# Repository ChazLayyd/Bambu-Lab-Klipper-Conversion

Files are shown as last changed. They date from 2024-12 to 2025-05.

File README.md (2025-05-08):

## Bambu Lab Klipper Conversion!

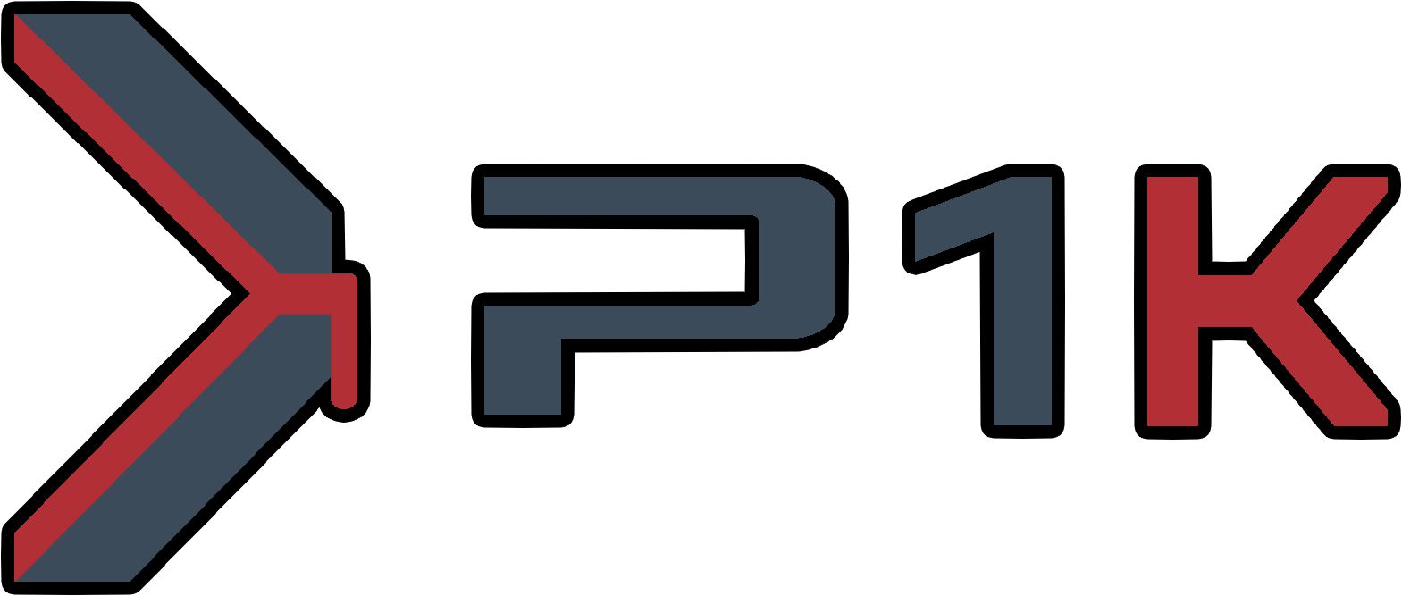
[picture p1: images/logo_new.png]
Klipper Logo


## Join the [**Community Discord!**](https://discord.gg/W6B5mBejuC)

## As requested multiple times- you can support the project on [**Ko-Fi**](https://ko-fi.com/chazmakes). It's not necessary, but if you want to help out then all support is greatly appreciated!

> [!Caution]
> This Project is in **BETA**, doing this conversion is fully at your own risk, I am not responsible for any damages done to your machine. This also will likely void your warranty.

Welcome to the Bambu Lab Klipper Conversion page! The project is in beta at the moment. This is a **non-destructive (PCB Only)**, or **destructive** upgrade path to [**Klipper**](https://www.klipper3d.org/), on a Bambu Lab P1 (or X1, untested). This means replacing the existing electronics with open-source hardware. A custom PCB has been designed to make everything plug and play with the fans, heatbed etc. The project runs on a fork of Klipper known as [**Kalico**](https://github.com/KalicoCrew/kalico), previously known as DangerKlipper. Make sure to get yourself familiarized with [**The Official Klipper Docs**](https://www.klipper3d.org/) and [**The Kalico Docs**](https://github.com/KalicoCrew/kalico/tree/main/docs)

You can find the BOM [**here**](https://docs.google.com/spreadsheets/d/187OusyREO98zsinT2Vspcr3hRtGYJvgfUr3D4DhnsbQ/edit?usp=sharing).

Find extensive documentation [**here**](https://docs.chazmakes.com/)!

The current release is <ins>**0.1** </ins>

## What works? (as of release <ins>**0.1**</ins>)
- ✓ The full hotend and extruder assembly
- ✓ Heatbed control with the Stock SSR
- ✓ The entire motion system is unchanged
- ✓ All fans work if wired correctly (PWM and Tach control needs to be added)
- ✓ Bambu Lab AMS does work via the [**OpenAMS project**](https://github.com/OpenAMSOrg)

## What doesn't work? (as of release <ins>**0.1**</ins>)
- ✖ Load cell probing (Replaced for now with a Biqu Microprobe), but a custom board is in the works.
- ✖ Webcam (You can purchase the X1C camera and wire it up as a USB camera)
- ✖ Stock display
- ✖ Toolhead boards
- ✖ Filament runout detection
- ✖ Not everything is plug and play. There is a PCB design available to make this non destructive You will need to splice on extension cables + JST XH 2.54 or DuPont 2.54 connectors.

## Why?

At first, this was a joke. More of a "why not" sort of thing. But as time went on, I really started to think of the benefits of putting Klipper on this machine. All my other printers run on Klipper.. so why not make the Bambu also run on Klipper! It provides a great platform for modding, such as adding extra fans, a nicer webcam, maybe some better controlled neopixel lighting, fully custom toolheads.. And most importantly, having the heatbed capable of running at 110C! Whatever you can think of, you can do it with this platform. It also completely eliminates the Bambu Cloud, allowing you to run everything locally, or even use your own cloud service.. Who else loves privacy?!

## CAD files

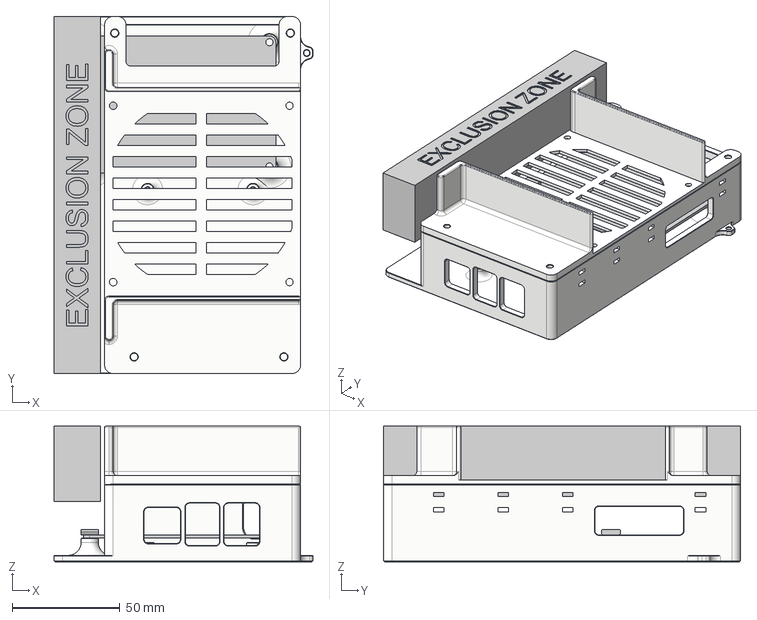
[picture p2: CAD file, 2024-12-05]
CAD/(UNTESTED)Fly D5 & Pi 3B etc.step
120.4 x 166.0 x 63.0 mm

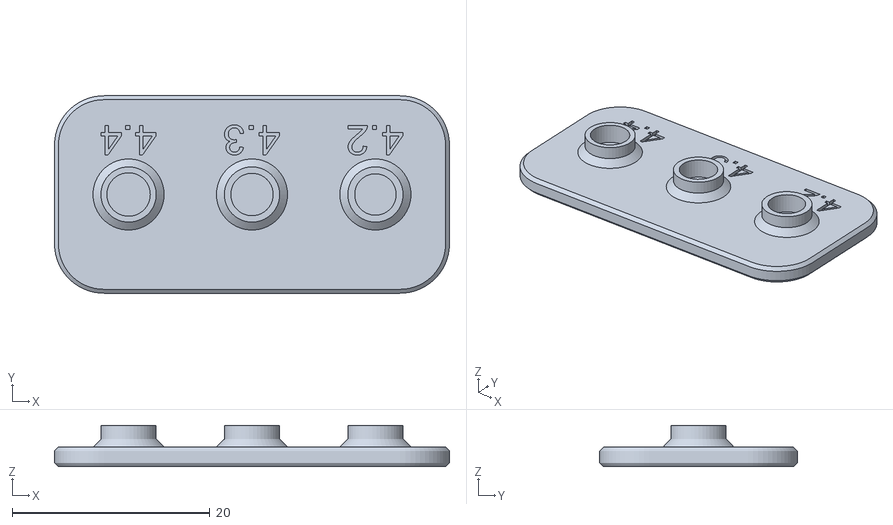
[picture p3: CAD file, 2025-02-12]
STL/Tolerance Test 4.2-4.4.stl
40.0 x 20.0 x 4.20

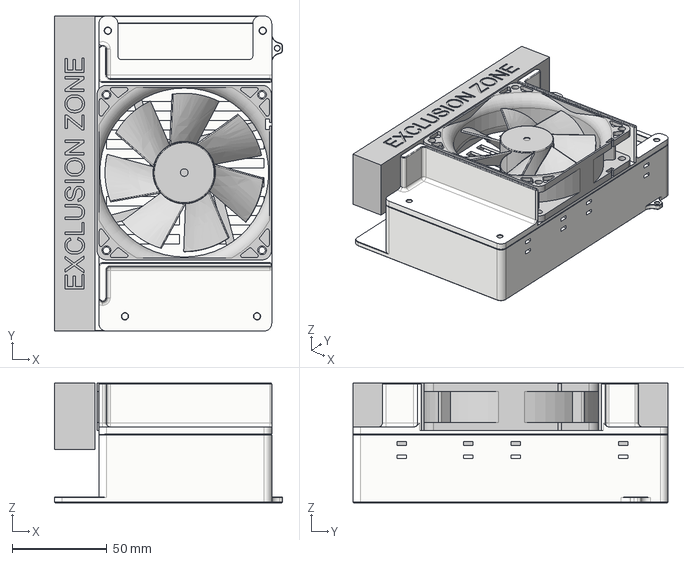
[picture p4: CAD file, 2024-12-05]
CAD/Generic Template Electronics Box.step
120.4 x 166.0 x 63.0 mm
Вентилятор 92мм Titan TFD-9225L12Z корпус
Вентилятор 92мм Titan TFD-9225L12Z крыльчатка

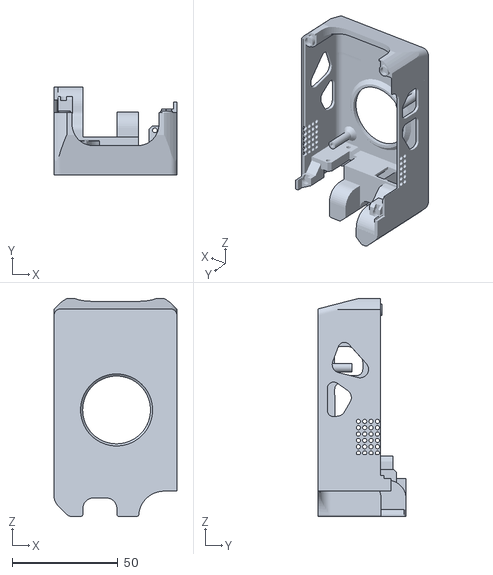
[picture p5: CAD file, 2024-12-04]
STL/Toolhead P1 NO LOGO.stl
58.0 x 41.8 x 103.0

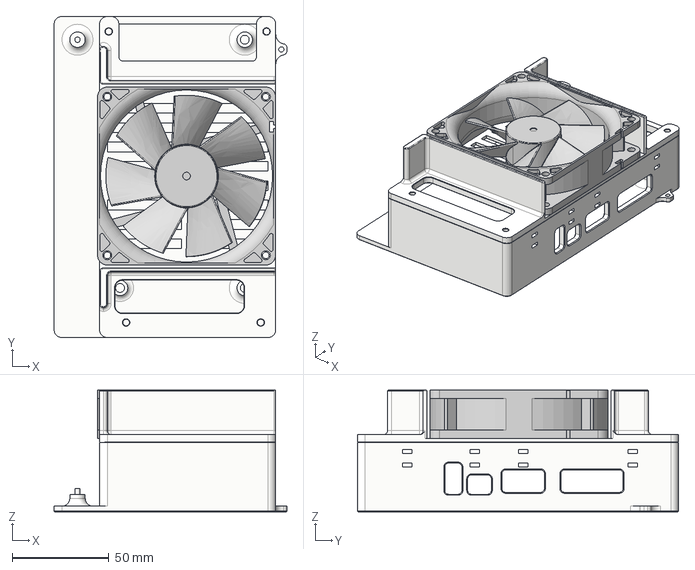
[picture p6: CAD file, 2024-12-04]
CAD/Manta M5P Electronics Box (BETA 0.1).step
120.4 x 166.0 x 63.0 mm
Вентилятор 92мм Titan TFD-9225L12Z корпус
Вентилятор 92мм Titan TFD-9225L12Z крыльчатка

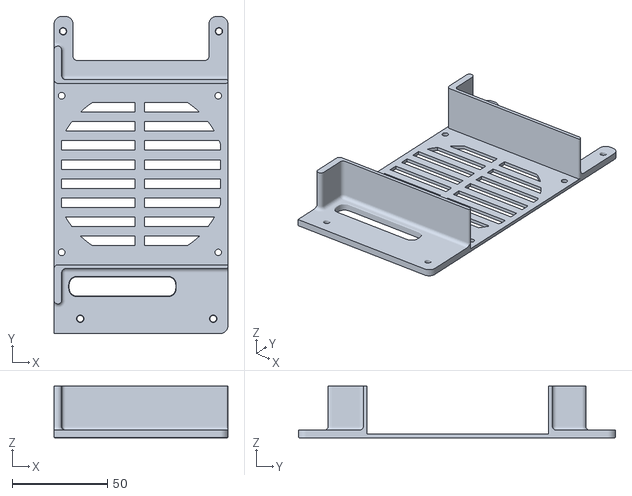
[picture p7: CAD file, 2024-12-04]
STL/Electronics Box Lid.stl
91.1 x 166.0 x 27.0

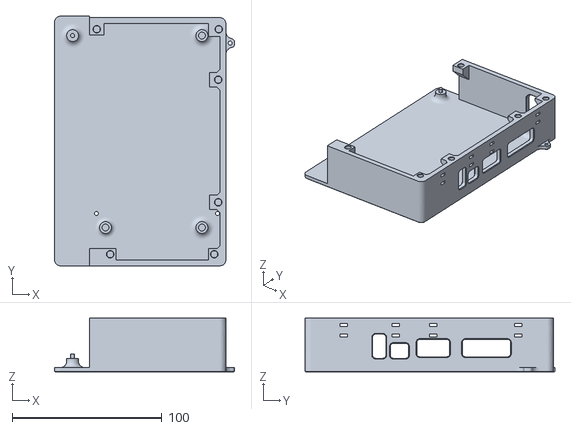
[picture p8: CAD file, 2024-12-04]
STL/Electronics Box M5P Beta 0.1.stl
120.4 x 167.0 x 36.0

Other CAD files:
CAD/Toolhead (BETA 0.1).step
STL/Toolhead P1.stl

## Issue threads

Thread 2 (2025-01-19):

Not an Issue, possibility of working on a1

DevCyclonekittenTriHex, 2025-01-19:
I am planning to attempt this on a bbl a1 printer.

My simple questions would be as follows:

- do p1 and a1 use the same motor connectors.

- do p1 and a1 use the same heat bed connector.

That's it. If I am successful, i will explain my method and possibly you can update the GitHub page to include an a1 / a1m section.

ChazLayyd, 2025-01-19:
Hey there, the A1 can probably be converted. I don't own one to tear it down. The P1 and A1 use the same bed but not sure about connectors sorry.

Closed 2025-01-19.

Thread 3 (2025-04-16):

original circuit boards

john-clark, 2025-04-16:
Why are you replacing the circuit boards? Why not flash the original boards?

ChazLayyd, 2025-04-17:
The original boards run on ESP32 and Spintrol chips which cannot be re-flashed. People have tried to do this but it is simply impossible.

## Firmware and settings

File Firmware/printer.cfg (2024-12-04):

# THIS IS A BETA PRINTER.CFG FILE FOR THE BAMBU LAB P1 KLIPPER PROJECT ON A BIGTREETECH MANTA M5P, THIS CFG MAY NOT BE FINAL. USE AT YOUR OWN RISK.

# This file contains common pin mappings for the BIGTREETECH Manta M5P
# To use this config, the firmware should be compiled for the
# STM32G0B1 with a "8KiB bootloader" "8 MHz crystal"
# and "USB (on PA11/PA12)" or "CAN bus (on PD0/PD1)".

# See docs/Config_Reference.md for a description of parameters.

########################################
# Printer and MCU configuration
########################################

[include mainsail.cfg]
[include macros.cfg]
[exclude_object]
[include KAMP_Settings.cfg]
#[include neopixel.cfg]
#[include moonraker_obico_macros.cfg]

[mcu host]
serial: /tmp/klipper_host_mcu

[mcu]
serial: /dev/serial/by-id/usb-Klipper_stm32g0b1xx_260049001950425938323120-if00

[printer]
kinematics: corexy
max_velocity: 400
max_accel: 15000
max_z_velocity: 15
max_z_accel: 100

[input_shaper]
shaper_freq_x: 66.2
shaper_type_x: mzv
shaper_freq_y: 56.0
shaper_type_y: mzv

#[force_move]
#enable_force_move: True

########################################
# Stepper Motor Configuration
########################################

[stepper_x]
step_pin: PA10
dir_pin: !PA14
enable_pin: !PA13
microsteps: 16
rotation_distance: 40
endstop_pin: tmc2209_stepper_x:virtual_endstop
position_endstop: 256
position_max: 256
homing_speed: 60
homing_retract_dist: 5

[stepper_y]
step_pin: PC6
dir_pin: !PC7
enable_pin: !PA9
microsteps: 16
rotation_distance: 40
endstop_pin: tmc2209_stepper_y:virtual_endstop
position_endstop: 0
position_max: 267
homing_speed: 60
homing_retract_dist: 0

[stepper_z]
step_pin: PB12
dir_pin: !PB11
enable_pin: !PA8
microsteps: 16
rotation_distance: 8
gear_ratio: 3:1
endstop_pin: probe:z_virtual_endstop
#position_endstop: 0.0
position_max: 250
position_min: -5
homing_speed: 10
second_homing_speed: 5
full_steps_per_rotation: 200

[extruder]
step_pin: PB0
dir_pin: !PB1
enable_pin: !PC4
microsteps: 16
rotation_distance: 0.825
gear_ratio: 9:53
nozzle_diameter: 0.400
filament_diameter: 1.750
heater_pin: PC5
sensor_type: ATC Semitec 104NT-4-R025H42G
sensor_pin: PA1
#control: mpc
heater_power: 48
cooling_fan: fan
filament_diameter: 1.75
filament_density: 1.25
filament_heat_capacity: 1.8 
#pid_Kp: 33.513
#pid_Ki: 14.895
#pid_Kd: 18.851
min_temp: -100
max_temp: 280
max_extrude_only_distance: 100
max_extrude_cross_section: 50

[tmc2209 stepper_x]
uart_pin: PD8
run_current: 1.2
hold_current: 0.6
diag_pin: ^PD2
driver_SGTHRS: 110
interpolate: True
stealthchop_threshold: 0
sense_resistor: 0.110

[tmc2209 stepper_y]
uart_pin: PB10
run_current: 1.2
hold_current: 0.6
diag_pin: ^PC3
driver_SGTHRS: 110
interpolate: True
stealthchop_threshold: 0
sense_resistor: 0.110

[tmc2209 stepper_z]
uart_pin: PB2
run_current: 0.500
hold_current: 0.5
diag_pin: PC3
interpolate: True
stealthchop_threshold: 0
sense_resistor: 0.110

[tmc2209 extruder]
uart_pin: PA6
run_current: 0.600
diag_pin: PC2
interpolate: False
sense_resistor: 0.110

########################################
# Bed Settings
########################################

[heater_bed]
heater_pin: PA7
sensor_type: Generic 3950
sensor_pin: PA0
#control: pid
#pid_Kp: 55
#pid_Ki: 2
#pid_Kd: 100
min_temp: 0
max_temp: 125
max_power: 0.5

########################################
# Fan Settings
########################################

## DEFINE THIS IF YOU PLAN TO USE THE AUX FAN.
#[fan_generic aux_fan]
#pin: host:gpiochip0/gpio17   # PWM pin for fan speed control
#max_power: 1.0        # Set maximum power to 100%
#cycle_time: 0.01        # Smooth PWM frequency
#shutdown_speed: 0       # Turn off the fan during shutdown

[fan] # Parts Cooling Fan
pin: PA3

[heater_fan Heatbreak_Cooling] # Heatbreak Cooling On The Hotend
pin: PA4
heater: extruder
heater_temp: 50.0
fan_speed: 1.0

[board_pins]
aliases:
    # EXP1 header
    EXP1_1=PD5, EXP1_3=PB3, EXP1_5=PB5, EXP1_7=PB7, EXP1_9=<GND>,
    EXP1_2=PD4,  EXP1_4=PD6, EXP1_6=PB4, EXP1_8=PB6, EXP1_10=<5V>,
    # EXP2 header
    EXP2_1=PB14, EXP2_3=PB8, EXP2_5=PC10, EXP2_7=PC12,  EXP2_9=<GND>,
    EXP2_2=PB13, EXP2_4=PB9, EXP2_6=PB15, EXP2_8=<RST>, EXP2_10=<NC>

# See the sample-lcd.cfg file for definitions of common LCD displays.

########################################
# Probe Settings (BIQU MICROPROBE)
########################################

[output_pin probe_enable]
pin: PC15
value: 0

[gcode_macro Probe_Deploy]
gcode:
  SET_PIN PIN=probe_enable VALUE=1

[gcode_macro Probe_Stow]
gcode:
  SET_PIN PIN=probe_enable VALUE=0

[probe]
pin: ^!PC13 # For V1 version, set to ^PC13 for high-level trigger; for V2 version, set to ^!PC13 for low-level trigger.
deactivate_on_each_sample: False
x_offset: 28.0 # Actual offset of the MicroProbe installation
y_offset: -15.0 # Actual offset of the MicroProbe installation
#z_offset: 0.0 # Actual offset of the MicroProbe installation
speed: 10
activate_gcode:
  Probe_Deploy
  G4 P500 # Allow 200 milliseconds for the probe to deploy
deactivate_gcode:
  Probe_Stow

########################################
# BED MESH, HOMING ETC.
########################################

[bed_mesh]
speed: 200
horizontal_move_z: 5
mesh_min: 38, 20
mesh_max: 238, 233
probe_count: 5, 5

[safe_z_home]
home_xy_position: 128, 128
speed: 200.0
z_hop: 10
z_hop_speed: 10.0

[screws_tilt_adjust]
screw1: 18, 45
screw1_name: front left screw
screw2: 200, 45
screw2_name: front right screw
screw3: 118, 230
screw3_name: rear right screw
horizontal_move_z: 5.
speed: 250.
screw_thread: CW-M5

########################################
# Other Settings / Unused
########################################

#[neopixel LED]
#pin: PC14
#chain_count:18
#   The number of Neopixel chips that are "daisy chained" to the
#   provided pin. The default is 1 (which indicates only a single
#   Neopixel is connected to the pin).
#color_order: GRB
#initial_RED: 0.5
#initial_GREEN: 0.0
#initial_BLUE: 0.5
#initial_WHITE: 1.0

#[neopixel my_neopixel2]
#pin: PC14

#[adxl345]
#cs_pin: PC0
#spi_bus: spi2

#[tmc2209 extruder1]
#uart_pin: PA6
#run_current: 0.600
#diag_pin:

#sensor_type:MAX31865
#sensor_pin: PA4
#spi_bus: spi1
#rtd_nominal_r: 100
#rtd_reference_r: 430
#rtd_num_of_wires: 2

#[filament_switch_sensor material_0]
#switch_pin: PC2

#[extruder1]
#step_pin: PB0
#dir_pin: PB1
#enable_pin: !PC4
#heater_pin: PA7
#sensor_pin: PA2
#...

# Proximity switch
#[probe]
#pin: PC15

#[bltouch]
#sensor_pin: PC13
#control_pin: PC15

#[heater_fan SoC_fan]
#pin: CB1: gpio79
#pin: RPI: gpio26

#*# <---------------------- SAVE_CONFIG ---------------------->
#*# DO NOT EDIT THIS BLOCK OR BELOW. The contents are auto-generated.
#*#
#*# [probe]
#*# z_offset = 1.610
#*#
#*# [bed_mesh default]
#*# version = 1
#*# points =
#*# 	  -0.015000, -0.015000, 0.004167
#*# 	  -0.028333, -0.039167, -0.008333
#*# 	  -0.030000, -0.047500, -0.015000
#*# x_count = 3
#*# y_count = 3
#*# mesh_x_pps = 2
#*# mesh_y_pps = 2
#*# algo = lagrange
#*# tension = 0.2
#*# min_x = 95.5
#*# max_x = 160.5
#*# min_y = 102.9
#*# max_y = 153.08
#*#
#*# [extruder]
#*# control = mpc
#*# block_heat_capacity = 6.03000
#*# sensor_responsiveness = 0.0992925
#*# ambient_transfer = 0.0744157
#*# fan_ambient_transfer = 0.0744157, 0.0769713, 0.0821679
#*#
#*# [heater_bed]
#*# control = pid
#*# pid_kp = 13.828
#*# pid_ki = 0.232
#*# pid_kd = 205.602
#*# pid_version = 1
#*# pid_target = 70.00
#*# pid_tolerance = 0.0200

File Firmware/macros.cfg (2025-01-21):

[gcode_macro START_PRINT]
gcode:
    {% set BED_TEMP = params.T_BED|default(60)|float %}
    {% set EXTRUDER_TEMP = params.T_EXTRUDER|default(240)|float %}
    
    # Set and wait for bed to reach temperature
    
    SET_HEATER_TEMPERATURE HEATER=heater_bed TARGET={BED_TEMP}
    TEMPERATURE_WAIT SENSOR=heater_bed MINIMUM={BED_TEMP-3} MAXIMUM={BED_TEMP+3}

    # Home X and Y axes in the correct order
    G28 X Y
    WIPE_NOZZLE

    # Home Z and perform bed mesh calibration
    G28 Z
    BED_MESH_CALIBRATE

    # Move to bucket to wait for hotend heating up
    
    G1 X60 Y240 F10000
    G1 Y267 F3000

    SET_HEATER_TEMPERATURE HEATER=extruder TARGET={EXTRUDER_TEMP}
    TEMPERATURE_WAIT SENSOR=extruder MINIMUM={EXTRUDER_TEMP-5}

    # Wipe nozzle

    G1 X95 F10000
    G1 X75 F10000
    G1 X95 F10000
    G1 X75 F10000
    G1 X95 F5000
    G1 X128 F10000
    G1 Y240 F10000

    # Purge Line

    LINE_PURGE

[gcode_macro END_PRINT]
gcode:
    # Ensure the printer is in absolute positioning
    G90
    # Move to the purge bucket position
    M104 S0 ## turn off hotend
    M140 S0 ## turn off bed
    M204
    M106 S0 ## turn off fans
    #G1 X60 Y240 F20000
    #G1 Y265 F3000
    #G1 E-5 F1000
    #G1 Z150 F1000
    #G1 X95 F10000
    #G1 X75 F10000
    #G1 X95 F10000
    #G1 X75 F10000
    G1 X128 F15000
    G1 Y240 F15000
    M84 ## disable motors
    BED_MESH_CLEAR

[gcode_macro UNLOAD_FILAMENT]
gcode:
    {% set EXTRUDER_TEMP = params.T_EXTRUDER|default(240)|float %}
    # Ensure the printer is in absolute positioning
    G90
    # Home X and Y axes in the correct order
    G28 X Y
    # Move to purge bucket
    G1 Y5 F1000
    G1 X60 Y240 F20000
    G1 Y267 F2000
    SET_HEATER_TEMPERATURE HEATER=extruder TARGET={EXTRUDER_TEMP}
    TEMPERATURE_WAIT SENSOR=extruder MINIMUM={EXTRUDER_TEMP-5}
    # Wipe then move to unload location
    G1 X95 F10000
    G1 X70 F10000
    G1 X95 F10000
    G1 X70 F10000
    G1 X120 F15000
    # Move to Filament cutter and cut the filament
    G1 X20.00 Y20.5 F25000
    G1 X20.00 Y0.5 F3000
    G1 X10.5 F100
    G1 X20 F1500
    G1 X60 F20000
    G1 Y240 F20000
    G1 Y265 F2000
    # Retract Filament
    G1 E-75 F1000

[gcode_macro LOAD_FILAMENT]
gcode:
    {% set EXTRUDER_TEMP = params.T_EXTRUDER|default(240)|float %}
    # Ensure the printer is in absolute positioning
    G90
    # Home X and Y axes
    G28 X Y
    # Move to purge bucket
    G1 Y5 F5000
    G1 X60 Y240 F20000
    G1 Y267 F3000
    # Set extruder temperature
    SET_HEATER_TEMPERATURE HEATER=extruder TARGET={EXTRUDER_TEMP}
    TEMPERATURE_WAIT SENSOR=extruder MINIMUM={EXTRUDER_TEMP-5}
    RESPOND TYPE=echo MSG="You have 15 seconds to load filament into the extruder."
    G4 P15000 #P15000  ; 15-second delay
    G92 E0
    G1 E70 F400
    M400
    M106 S255
    M104 S0
    TEMPERATURE_WAIT SENSOR=extruder MAXIMUM={EXTRUDER_TEMP-30}
    # Prompt and delay for filament loading
    SET_HEATER_TEMPERATURE HEATER=extruder TARGET=140
    TEMPERATURE_WAIT SENSOR=extruder MINIMUM=145
    G1 X70 F15000
    G1 X76
    G1 X65
    G1 X76
    G1 X65
    G1 X90 F3000
    G1 Y255
    G1 X100
    G1 Y267
    G1 X70 F10000
    G1 X100 F5000
    G1 X70 F10000
    G1 X100 F5000
    G1 X70 F10000
    G1 X100 F5000
    G1 X128 F12000
    G1 Y180 F15000
    SET_HEATER_TEMPERATURE HEATER=extruder TARGET=140
    M117 "Filament loaded!"
    M400
    M106 P2 S0

[gcode_macro WIPE_NOZZLE]
gcode:
    {% set EXTRUDER_TEMP = params.T_EXTRUDER|default(220)|float %}
    # Move to purge bucket
    G1 X60 Y240 F15000
    G1 Y267 F3500

    # Set extruder temperature
    SET_HEATER_TEMPERATURE HEATER=extruder TARGET={EXTRUDER_TEMP}
    TEMPERATURE_WAIT SENSOR=extruder MINIMUM={EXTRUDER_TEMP-5}
    G92 E0
    G1 E70 F400
    M400
    M106 S255
    M104 S0
    TEMPERATURE_WAIT SENSOR=extruder MAXIMUM={EXTRUDER_TEMP-30}

    # Wipe the nozzle
    G1 X70 F9000
    G1 X78 F15000
    G1 X65 F15000
    G1 X78 F15000
    G1 X65 F15000
    G1 X75 F6000
    G1 X95 F15000
    G1 X75 F15000
    G1 X95 F15000
    G1 X75 F15000
    G1 X95 F15000
    G1 X75 F15000
    G1 X165 F15000
    G4 P500
    G1 X65 Y230 F18000
    G1 Y264 F6000
    G4 P2000
    G1 X95 F15000
    G1 X75 F15000
    G1 X75 F15000
    G1 X75 F15000
    G1 X128
    G1 Y128 F20000
    
    M400
    M106 P2 S0

[gcode_macro SPEED_TEST_BALLS]
gcode:

  g28
  g1 z30 f500
  g1 x40 y40 f30000
  g1 x210 y210
  g1 x40 y40
  g1 x210
  g1 x40 y210
  g1 x210 y40
  g1 x40
  g1 y210
  g1 x210
  g1 y40
  g1 x125 y125
  g1 x150 y150
  g1 x125 y125
  g1 x150
  g1 x125 y150
  g1 x150 y125
  g1 x125
  g1 y150
  g1 x150
  g1 y125
  g1 x40 y40
  g1 x210 y210
  g1 x40 y40
  g1 x210
  g1 x40 y210
  g1 x210 y40
  g1 x40
  g1 y210
  g1 x210
  g1 y40
  g1 x125 y125
  g1 x150 y150
  g1 x125 y125
  g1 x150
  g1 x125 y150
  g1 x150 y125
  g1 x125
  g1 y150
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

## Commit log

2024-12-04 Add Electronics Box & Lid to Main
    [Electronics Box Lid.stl, Electronics Box M5P Beta 0.1.stl]
2024-12-04 Add Manta M5P Electronics Box to main
    [Manta M5P Electronics Box (BETA 0.1).step]
2024-12-04 Gerber PCB file to main.
2024-12-04 add klipper files to main
    [mainsail.cfg, timelapse.cfg]
2024-12-04 Add Toolhead STL & No Logo Version
    [Toolhead P1 NO LOGO.stl, Toolhead P1.stl]
2024-12-04 Add toolhead .STEP to main
    [Toolhead (BETA 0.1).step]
2024-12-05 Add template electronics box
    [Generic Template Electronics Box.step]
2024-12-05 Added untested Fly D5 & Pi3B etc cad file.
    [(UNTESTED)Fly D5 & Pi 3B etc.step]
2025-01-21 added macros.cfg
    because im an idiot and forgot this a month ago
    [macros.cfg]
2025-02-05 Add new, untested lightweight fan covers.
    Add new, untested lightweight fan covers that offer both standard and heat set insert variants, with and without text / logos.
2025-02-05 Update Fan Cover.step
2025-02-12 Add tolerance test
    [Tolerance Test 4.2-4.4.stl]
